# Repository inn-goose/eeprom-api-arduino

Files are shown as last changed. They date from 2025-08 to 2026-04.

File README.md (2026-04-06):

# Arduino EEPROM Programmer for AT28C64 / AT28C256

An Arduino-based parallel EEPROM programmer for the AT28Cxx chip family (AT28C04, AT28C16, AT28C64, AT28C256) with a Python CLI. Validated on Arduino MEGA and DUE. Useful for [Ben Eater's breadboard computer](https://eater.net/) projects and similar builds.

> [!CAUTION]
> During **read** and **standalone verify** operations, the chip's `!WE` pin **MUST** be connected to `VCC` using a jumper wire to prevent data corruption from Arduino's reset behavior. The `--write` command includes in-session verify and does not require the jumper. [Details](https://goose.sh/blog/eeprom-programmer-5-data-corruption/)

> [!IMPORTANT]
> This project concerns **external** EEPROM chips, not the built-in Arduino EEPROM memory.

The firmware is flashed onto an Arduino MEGA or DUE. The EEPROM chip is connected to the extended pin header (pins 22-53), and the Python CLI communicates over a binary serial protocol to erase, write, read, and verify binary data. The CLI interface is modeled after [`minipro`](https://formulae.brew.sh/formula/minipro) (XGecu programmer).

A companion blog series documents the development: [EEPROM Programmer posts on goose.sh](https://goose.sh/tags/eeprom-programmer/).

## Supported Chips

* `AT28C04 @ DIP24`, [datasheet](https://www.tvsat.com.pl/pdf/A/at28c04_atm.pdf)
* `AT28C16 @ DIP24`, [datasheet](http://cva.stanford.edu/classes/cs99s/datasheets/at28c16.pdf)
* `AT28C64 @ DIP28`, [datasheet](https://ww1.microchip.com/downloads/en/devicedoc/doc0001H.pdf)
* `AT28C256 @ DIP28`, [datasheet](https://ww1.microchip.com/downloads/en/DeviceDoc/doc0006.pdf)

Details in the [EEPROM Programmer: Supported Chips](https://goose.sh/blog/eeprom-programmer-8-supported-chips/) post.

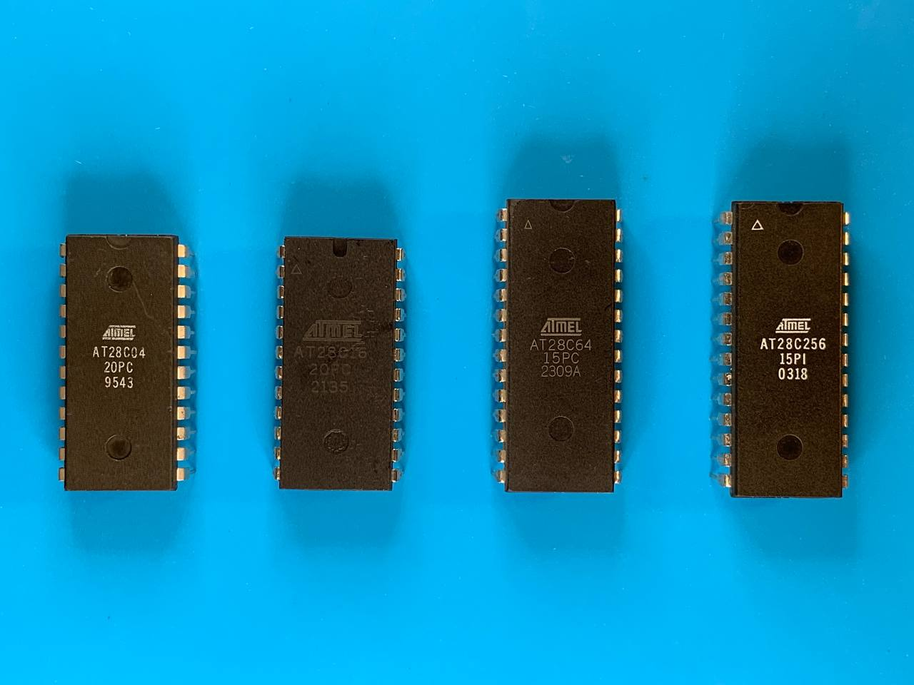
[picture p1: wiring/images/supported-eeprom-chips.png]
Supported EEPROM Chips


## Performance

The programmer's performance is strongly dependent on the Arduino platform; the DUE is ~30% faster than the MEGA for reads, and significantly faster for writes due to page write support. The performance measurement details are described in the [EEPROM Programmer Performance](https://goose.sh/blog/eeprom-programmer-8-supported-chips/#eeprom-programmer-performance) post.

### Arduino DUE, 84 MHz (binary protocol)

| Chip | Size | Read (sec) | Erase + Write + Verify (sec) |
| -- | :--: | :--: | :--: |
| AT28C64 | 8K x 8 | 1.6 | 12.7 |

### Arduino DUE, 84 MHz (JSON-RPC, legacy)

| Chip | Size | Full Memory Read (sec) | Full Memory Write (sec) |
| -- | :--: | :--: | :--: |
| AT28C04 | 512 x 8 | 0.9 | 1.4 |
| AT28C16 | 2K x 8 | 3.6 | 11 |
| AT28C64 | 8K x 8 | 15 | 22 |
| AT28C256 | 32K x 8 | 56 | 85* |

(*) if [page write](https://goose.sh/blog/eeprom-programmer-7-page-write/) mode is enabled.

### Arduino MEGA, 16 MHz (JSON-RPC, legacy)

| Chip | Size | Full Memory Read (sec) | Full Memory Write (sec) |
| -- | :--: | :--: | :--: |
| AT28C04 | 512 x 8 | 1.4 | 1.8 |
| AT28C16 | 2K x 8 | 5.5 | 14 |
| AT28C64 | 8K x 8 | 21 | 28* |
| AT28C256 | 32K x 8 | 84 | 305 |

(*) if [RDY/!BUSY polling](https://goose.sh/blog/eeprom-programmer-6-data-polling-vs-rdy-busy/#rdybusy-pin-polling) mode is enabled

## Data Corruption and Read-Only Jumper Wire

Communication over the Serial protocol can corrupt data stored in the EEPROM memory, despite the **Hardware Protection** claimed in the datasheet. This issue is analyzed in detail in the [Data Corruption on Arduino Serial Connection Reset](https://goose.sh/blog/eeprom-programmer-5-data-corruption/) post.

To prevent data corruption, the Read-Only jumper wire should always be used during read operations, as shown in the wiring diagrams. The jumper should be removed only when writing data to the chip.

The `--write` command performs erase, write, and verify in a single serial session without reconnecting, so the jumper is not needed for write+verify operations.

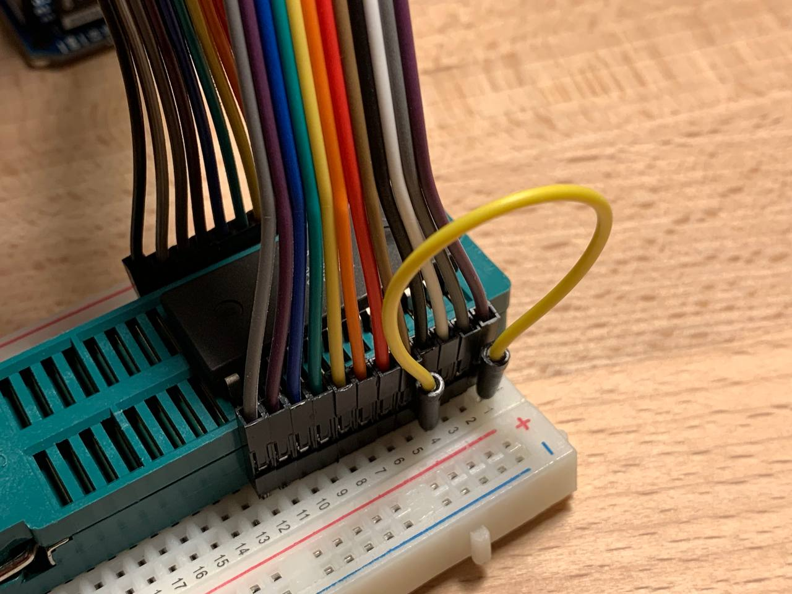
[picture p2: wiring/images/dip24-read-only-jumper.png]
Read Only Jumper Wire


## Wiring

The Programmer supports two chip wiring variants: `DIP24` and `DIP28`. Each type requires its own wiring configuration and a recompilation of the code. Below is a mapping table along with the section of code that must be adjusted accordingly.

| Wiring Type | Supported Chips |
| -- | -- |
| DIP24 | AT28C04, AT28C16 |
| DIP28 | AT28C64, AT28C256 |

file: [./eeprom_programmer/eeprom_programmer.ino](./eeprom_programmer/eeprom_programmer.ino)
```cpp
// EEPROM Programmer

// specify the wiring type here
// * DIP24
// * DIP28
static EepromProgrammer eeprom_programmer(BoardWiringType::DIP24);
// static EepromProgrammer eeprom_programmer(BoardWiringType::DIP28);
```

The wiring configuration can be reconfigured in the file [./eeprom_programmer/board_wiring.h](./eeprom_programmer/board_wiring.h)

### DIP24 wiring

The pins are arranged sequentially to simplify wiring. On one side, the pins start with GND, and on the other with VCC, eliminating the need for separate power wires.

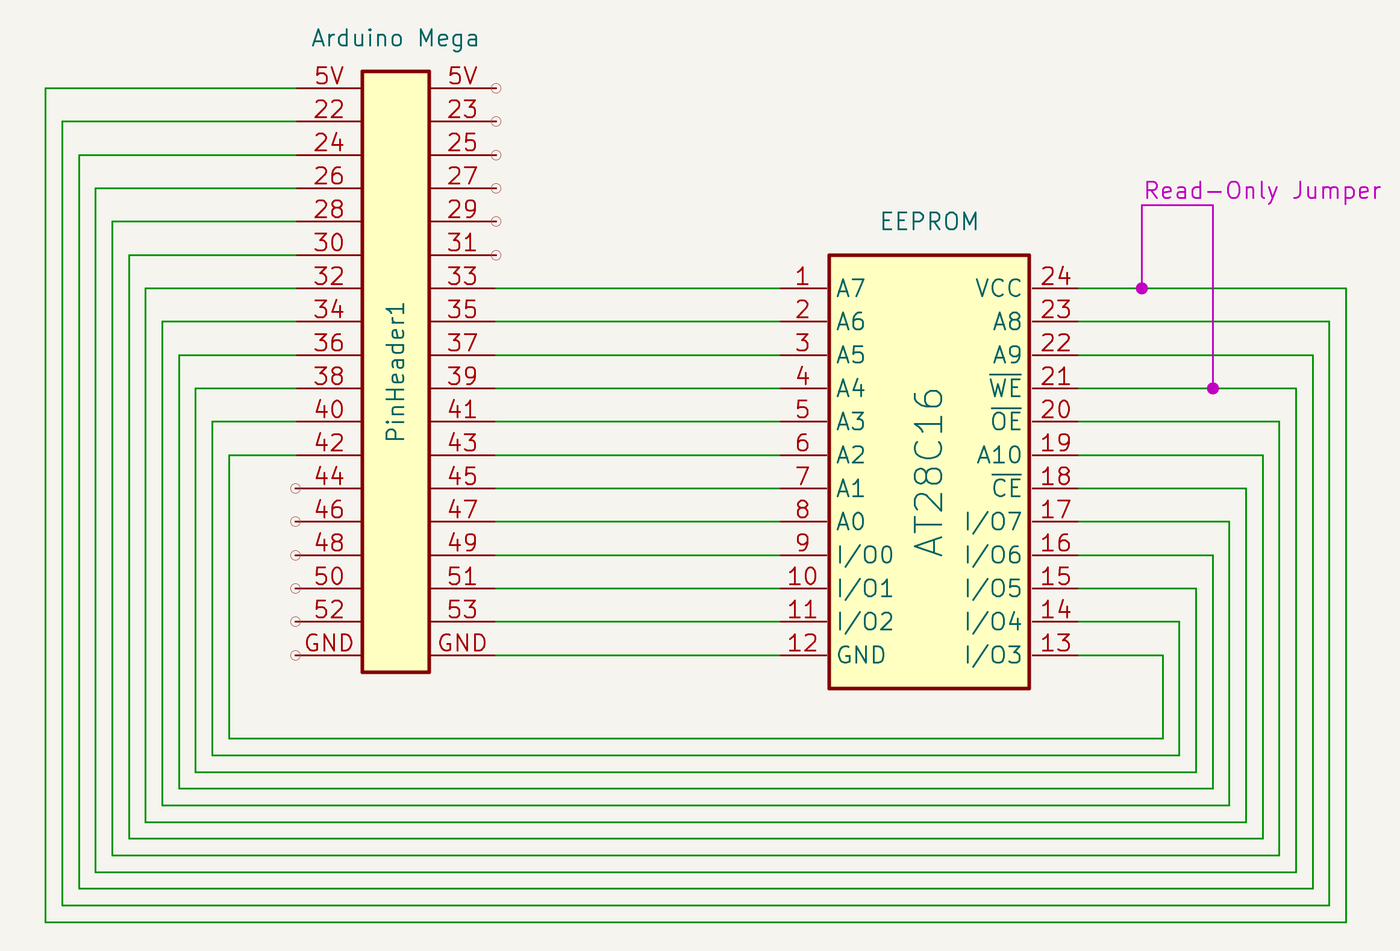
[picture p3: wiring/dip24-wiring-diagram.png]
EEPROM Programmer Wiring DIP24 Diagram


### DIP28 wiring

For the `DIP28` variant, two additional wires are added on each side.

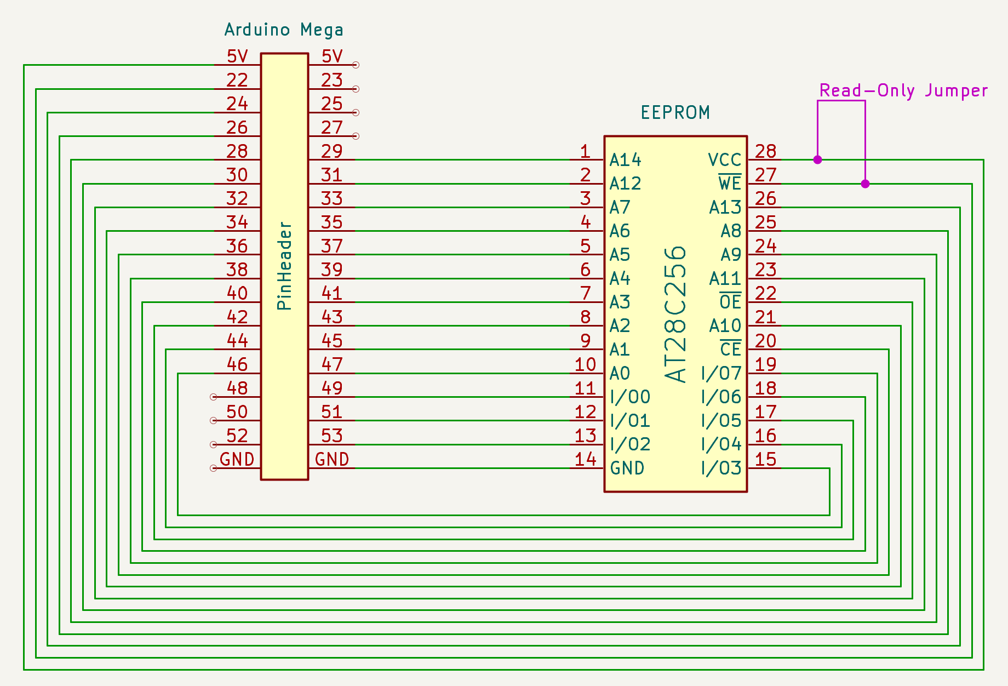
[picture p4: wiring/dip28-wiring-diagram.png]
EEPROM Programmer Wiring DIP28 Diagram


### Wiring example

In the photographs, a short breadboard was used for the `DIP24` wiring, along with two ribbon cables and a ZIF socket for convenience. This setup is not mandatory: simple jumper wires can be used instead, and the chip may be placed directly into the breadboard.

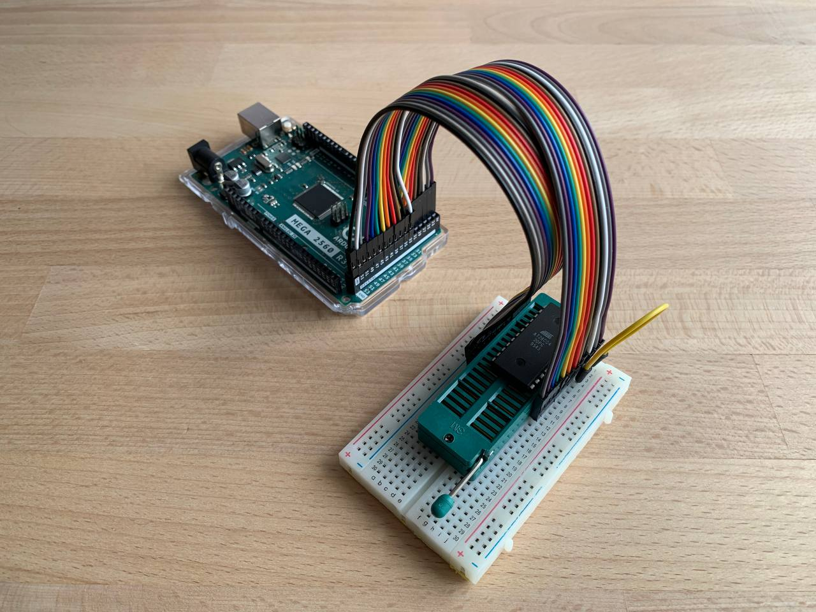
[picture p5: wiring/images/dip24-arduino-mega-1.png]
DIP24 Wiring with Arduino MEGA

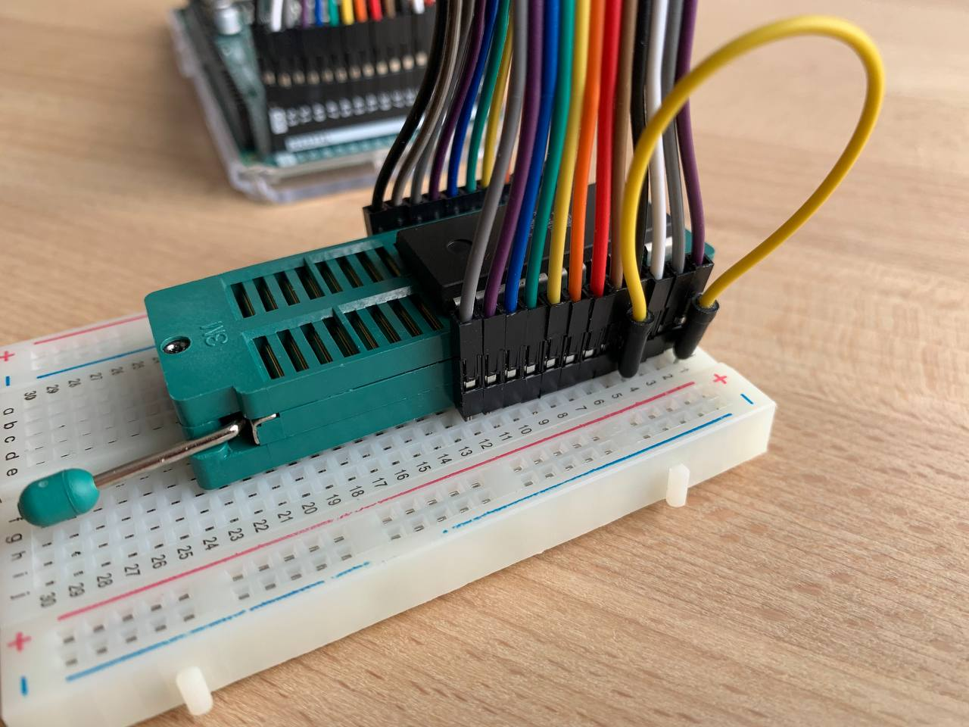
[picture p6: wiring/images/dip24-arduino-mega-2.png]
DIP24 Wiring with Arduino MEGA

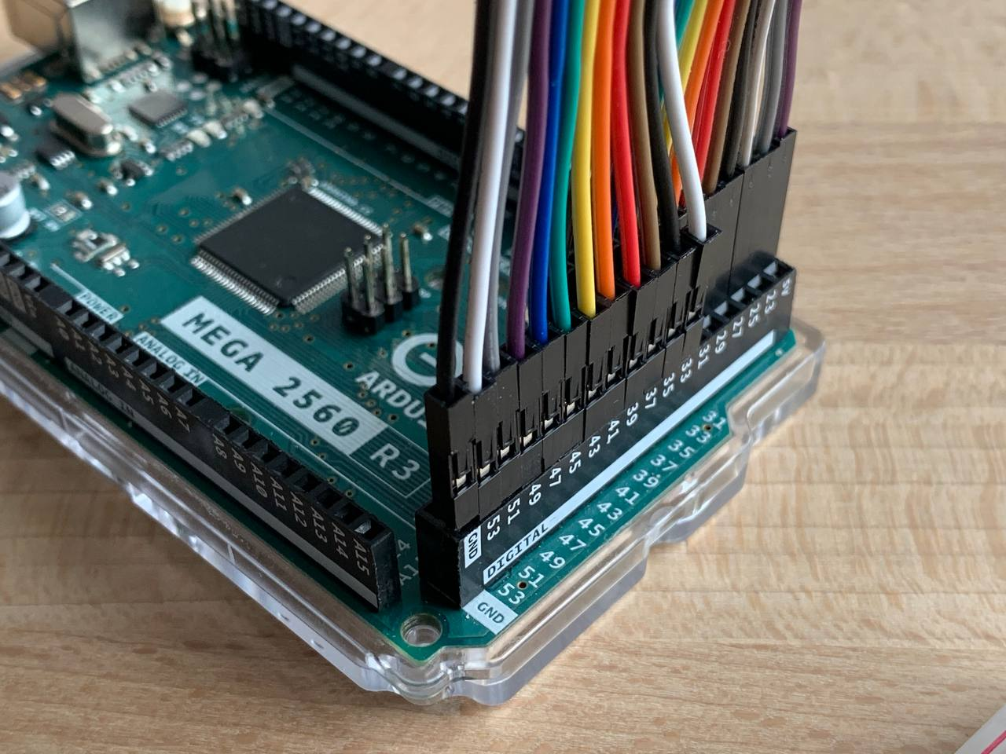
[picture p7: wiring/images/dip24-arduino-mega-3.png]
DIP24 Wiring with Arduino MEGA


## Programming EEPROM Chips with CLI

A Python CLI enables reading and writing large volumes of data. When using only the Arduino, it is not possible to program a 64 KB chip, as this does not fit into the MEGA's memory.

The CLI communicates with the firmware over a binary serial protocol with CRC-16 integrity checking. The previous JSON-RPC implementation is described in the [Implementing Serial JSON-RPC API](https://goose.sh/blog/eeprom-programmer-4-serial-json-rpc-api/) post.

### Initialization

```bash
pip3 install virtualenv

# get the python version
python --version
...
Python 3.9.6

# specify python version here (use only X.Y part)
PATH=${PATH}:~/Library/Python/3.9/bin/ ./env/init.sh

# activate the newly created venv
source venv/bin/activate

# add the CLI library to the python path
export PYTHONPATH=./eeprom_programmer_cli/:$PYTHONPATH
```

### Serial port selection

The CLI must be provided with the port to which the Arduino is connected. The port name can be found in the Arduino IDE or obtained by listing available ports using the following command:

```bash
python3 -m serial.tools.list_ports
...
/dev/cu.usbmodem2101
```

### Supported commands

The CLI interface closely resembles the `minipro` interface used with *XGecu* programmers.

#### read

```bash
# read data from the chip memory and write it to a binary file
./eeprom_programmer_cli/cli.py /dev/cu.usbmodem2101 -p AT28C64 --read tmp/dump_eeprom.bin

# read the binary file content with xxd
xxd tmp/dump_eeprom.bin | less
```

#### erase

```bash
# erase the chip memory with the specific pattern
./eeprom_programmer_cli/cli.py /dev/cu.usbmodem2101 -p AT28C64 --erase --erase-pattern FF
```

#### write

The `--write` command performs erase + write + verify in a single serial session. Verify runs automatically after writing, without reconnecting to the board.

```bash
# erase + write + verify (default)
./eeprom_programmer_cli/cli.py /dev/cu.usbmodem2101 -p AT28C64 --write test_bin/64_the_red_migration.bin

# skip verify after write
./eeprom_programmer_cli/cli.py /dev/cu.usbmodem2101 -p AT28C64 --write test_bin/64_the_red_migration.bin --skip-verify

# do not erase the chip content before the write operation
./eeprom_programmer_cli/cli.py /dev/cu.usbmodem2101 -p AT28C64 --write test_bin/64_the_red_migration.bin --skip-erase

# use custom erase pattern
./eeprom_programmer_cli/cli.py /dev/cu.usbmodem2101 -p AT28C64 --write test_bin/64_the_red_migration.bin --erase-pattern CC
```

#### verify

Standalone verify reads the chip and compares against a binary file. Requires the `!WE` jumper wire to prevent data corruption on reconnect.

```bash
# read data and verify it against the binary file
./eeprom_programmer_cli/cli.py /dev/cu.usbmodem2101 -p AT28C64 --verify test_bin/64_the_red_migration_AT28C64_ff.bin
```

## Troubleshooting

### Programmer error codes

Check [./eeprom_programmer/eeprom_programmer_lib.h](./eeprom_programmer/eeprom_programmer_lib.h) for error codes:
```cpp
enum ErrorCode : short {
  SUCCESS = 0,
  ...
```

### Failed to init AT28C256 chip with error: 12

An unknown chip type, or a mismatch between the wiring configuration and the selected chip type. Check the DIP24 or DIP28 wiring.

```bash
init device: failed, failed to init AT28C256 chip with: error response: {'code': -32010, 'message': 'Programmer error', 'data': 'Failed to init AT28C256 chip with error: 12'}
```

On startup, the CLI reports the board wiring type that the programmer firmware was built with:
```bash
programmer_settings: {'board_wiring_type': 24, 'max_page_size': 64}
```

## Testing

### Basic CLI tests

#### prepare

```bash
source venv/bin/activate
export PYTHONPATH=./eeprom_programmer_cli/:$PYTHONPATH
```

#### write + verify (in-session)

No jumper swapping needed. The `--write` command performs erase, write, and verify in a single serial session.

```bash
./eeprom_programmer_cli/cli.py /dev/cu.usbmodem2101 -p AT28C64 --write test_bin/64_the_red_migration_AT28C64_ff.bin --collect-performance
```

#### erase

```bash
# >> remove jumper wire
./eeprom_programmer_cli/cli.py /dev/cu.usbmodem2101 -p AT28C64 --erase --erase-pattern BB --collect-performance

# >> set jumper wire
./eeprom_programmer_cli/cli.py /dev/cu.usbmodem2101 -p AT28C64 --read tmp/dump_eeprom.bin

xxd tmp/dump_eeprom.bin | less
```

#### write and read

```bash
# >> remove jumper wire
./eeprom_programmer_cli/cli.py /dev/cu.usbmodem2101 -p AT28C64 --write test_bin/64_the_red_migration.bin --erase-pattern BB --collect-performance

# >> set jumper wire
./eeprom_programmer_cli/cli.py /dev/cu.usbmodem2101 -p AT28C64 --read tmp/dump_eeprom.bin

xxd tmp/dump_eeprom.bin > tmp/dump_eeprom.hex
vimdiff tmp/dump_eeprom.hex tmp/64_the_red_migration.hex
```

#### standalone verify

```bash
# >> remove jumper wire
./eeprom_programmer_cli/cli.py /dev/cu.usbmodem2101 -p AT28C64 --write test_bin/64_the_red_migration.bin --skip-verify --collect-performance

# >> set jumper wire
./eeprom_programmer_cli/cli.py /dev/cu.usbmodem2101 -p AT28C64 --verify test_bin/64_the_red_migration_AT28C64_ff.bin
```

### Performance testing with CLI

```bash
# AT28C04
./eeprom_programmer_cli/cli.py /dev/cu.usbmodem2101 -p AT28C04 --erase --erase-pattern 11 --collect-performance
./eeprom_programmer_cli/cli.py /dev/cu.usbmodem2101 -p AT28C04 --read tmp/dump_eeprom.bin --collect-performance && xxd tmp/dump_eeprom.bin | less
./eeprom_programmer_cli/cli.py /dev/cu.usbmodem2101 -p AT28C04 --write test_bin/4_journey_of_luna_AT28C04_ff.bin --skip-erase --collect-performance
./eeprom_programmer_cli/cli.py /dev/cu.usbmodem2101 -p AT28C04 --verify test_bin/4_journey_of_luna_AT28C04_ff.bin --collect-performance

# AT28C16
./eeprom_programmer_cli/cli.py /dev/cu.usbmodem2101 -p AT28C16 --erase --erase-pattern 11 --collect-performance
./eeprom_programmer_cli/cli.py /dev/cu.usbmodem2101 -p AT28C16 --read tmp/dump_eeprom.bin --collect-performance && xxd tmp/dump_eeprom.bin | less
./eeprom_programmer_cli/cli.py /dev/cu.usbmodem2101 -p AT28C16 --write test_bin/16_geese_in_space_AT28C16_ff.bin --skip-erase --collect-performance
./eeprom_programmer_cli/cli.py /dev/cu.usbmodem2101 -p AT28C16 --verify test_bin/16_geese_in_space_AT28C16_ff.bin --collect-performance

# AT28C64
./eeprom_programmer_cli/cli.py /dev/cu.usbmodem2101 -p AT28C64 --erase --erase-pattern 11 --collect-performance
./eeprom_programmer_cli/cli.py /dev/cu.usbmodem2101 -p AT28C64 --read tmp/dump_eeprom.bin --collect-performance && xxd tmp/dump_eeprom.bin | less
./eeprom_programmer_cli/cli.py /dev/cu.usbmodem2101 -p AT28C64 --write test_bin/64_the_red_migration_AT28C64_ff.bin --skip-erase --collect-performance
./eeprom_programmer_cli/cli.py /dev/cu.usbmodem2101 -p AT28C64 --verify test_bin/64_the_red_migration_AT28C64_ff.bin --collect-performance

# AT28C256
./eeprom_programmer_cli/cli.py /dev/cu.usbmodem2101 -p AT28C256 --erase --erase-pattern 11 --collect-performance
./eeprom_programmer_cli/cli.py /dev/cu.usbmodem2101 -p AT28C256 --read tmp/dump_eeprom.bin --collect-performance && xxd tmp/dump_eeprom.bin | less
./eeprom_programmer_cli/cli.py /dev/cu.usbmodem2101 -p AT28C256 --write test_bin/256_the_geometry_of_flight_AT28C256_ff.bin --skip-erase --collect-performance
./eeprom_programmer_cli/cli.py /dev/cu.usbmodem2101 -p AT28C256 --verify test_bin/256_the_geometry_of_flight_AT28C256_ff.bin --collect-performance
```

### Using XGecu programmer as a reference

Use the [`minipro`](https://formulae.brew.sh/formula/minipro) utility to perform read and write operations with the XGecu programmer

```bash
brew install minipro

# write the "real" dump to the chip
minipro --device AT28C64 -s -u --write test_bin/64_the_red_migration.bin
minipro --device AT28C256 -s -u --write test_bin/256_the_geometry_of_flight.bin

# read the data
minipro --device AT28C64 -u --read tmp/dump_xgecu.bin
minipro --device AT28C256 -u --read tmp/dump_xgecu.bin

# convert to HEX
xxd tmp/dump_xgecu.bin > tmp/dump_xgecu.hex

# compare
vimdiff tmp/dump_eeprom.hex tmp/dump_xgecu.hex
```

### JSON-RPC API (legacy, no longer active)

The firmware previously used JSON-RPC over serial. These commands no longer work with the current binary protocol firmware but are preserved here for reference. See the [Implementing Serial JSON-RPC API](https://goose.sh/blog/eeprom-programmer-4-serial-json-rpc-api/) post for details.

Set Arduino IDE's *Serial Monitor* on `115200` baud

`init_chip(chip_type: str)`
```json
{"jsonrpc":"2.0", "id":0, "method": "init_chip", "params": ["AT28C64"]}
```

`set_read_mode(page_size_bytes: int)`
```json
{"jsonrpc":"2.0", "id":0, "method": "set_read_mode", "params": [4]}
```

`read_page(page_no: int)`
```json
{"jsonrpc":"2.0", "id":0, "method": "read_page", "params": [0]}
```

`set_write_mode(page_size_bytes: int)`
```json
{"jsonrpc":"2.0", "id":0, "method": "set_write_mode", "params": [4]}
```

`write_page(page_no: int, data: array[int])`
```json
{"jsonrpc":"2.0", "id":0, "method": "write_page","params": [0, [127, 127, 127, 127]]}
```

#### write operation sequence

```json
{"jsonrpc":"2.0", "id":0, "method": "init_chip", "params": ["AT28C64"]}
{"jsonrpc":"2.0", "id":0, "method": "set_write_mode", "params": [4]}
{"jsonrpc":"2.0", "id":0, "method": "write_page","params": [0, [120, 130, 140, 150]]}
{"jsonrpc":"2.0", "id":0, "method": "write_page","params": [50, [20, 30, 40, 50]]}
{"jsonrpc":"2.0", "id":0, "method": "get_write_perf","params": []}
```

#### read operation sequence

```json
{"jsonrpc":"2.0", "id":0, "method": "init_chip", "params": ["AT28C64"]}
{"jsonrpc":"2.0", "id":0, "method": "set_read_mode", "params": [4]}
{"jsonrpc":"2.0", "id":0, "method": "read_page", "params": [0]}
{"jsonrpc":"2.0", "id":0, "method": "read_page", "params": [50]}
```

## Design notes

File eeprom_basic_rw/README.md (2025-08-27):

# EEPROM 28C64 Basic RW Example for Arduino

## Init

set pins layout in `eeprom_wiring.h`

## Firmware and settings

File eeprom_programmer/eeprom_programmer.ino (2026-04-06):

#include "board_wiring.h"
#include "eeprom_programmer_lib.h"
#include "binary_protocol.h"

using namespace EepromProgrammerLibrary;
using namespace BoardWiring;
using namespace BinaryProtocol;


// EEPROM Programmer

// specify the wiring type here
// * DIP24
// * DIP28
// static EepromProgrammer eeprom_programmer(BoardWiringType::DIP24);
static EepromProgrammer eeprom_programmer(BoardWiringType::DIP28);


// Binary Protocol Processor

static BinaryProtocolBoard binary_board(command_handler);

void command_handler(uint8_t cmd, uint8_t seq, const uint8_t* payload, uint16_t payload_len) {
  if (cmd == CMD_INIT_CHIP) {
    // payload: chip_name (null-terminated string)
    if (payload_len < 1) {
      binary_board.send_error(cmd, seq, ErrorCode::CHIP_NOT_SUPPORTED, "empty chip name");
      return;
    }
    const char* chip_name = (const char*)payload;

    ErrorCode code = eeprom_programmer.init_chip(String(chip_name));
    if (code != ErrorCode::SUCCESS) {
      char buf[50];
      snprintf(buf, sizeof(buf), "init failed: %d", code);
      binary_board.send_error(cmd, seq, code, buf);
      return;
    }

    // response payload: memory_size as uint32 LE (explicit serialization)
    uint32_t mem_size = eeprom_programmer.get_memory_size_bytes();
    uint8_t mem_size_le[4] = {
      (uint8_t)(mem_size & 0xFF),
      (uint8_t)((mem_size >> 8) & 0xFF),
      (uint8_t)((mem_size >> 16) & 0xFF),
      (uint8_t)((mem_size >> 24) & 0xFF),
    };
    binary_board.send_response(cmd, seq, mem_size_le, 4);

  } else if (cmd == CMD_SET_READ_MODE) {
    // payload: page_size as uint16 LE
    if (payload_len < 2) {
      binary_board.send_error(cmd, seq, ErrorCode::INVALID_PAGE_SIZE, "missing page_size");
      return;
    }
    uint16_t page_size = payload[0] | ((uint16_t)payload[1] << 8);

    ErrorCode code = eeprom_programmer.set_read_mode(page_size);
    if (code != ErrorCode::SUCCESS) {
      char buf[50];
      snprintf(buf, sizeof(buf), "set_read_mode failed: %d", code);
      binary_board.send_error(cmd, seq, code, buf);
      return;
    }

    binary_board.send_response(cmd, seq, nullptr, 0);

  } else if (cmd == CMD_READ_PAGE) {
    // payload: page_no as uint16 LE
    if (payload_len < 2) {
      binary_board.send_error(cmd, seq, ErrorCode::INVALID_PAGE_NO, "missing page_no");
      return;
    }
    uint16_t page_no = payload[0] | ((uint16_t)payload[1] << 8);

    const size_t page_size = eeprom_programmer.get_page_size_bytes();
    uint8_t buffer[page_size];

    ErrorCode code = eeprom_programmer.read_page(page_no, buffer);
    if (code != ErrorCode::SUCCESS) {
      char buf[50];
      snprintf(buf, sizeof(buf), "read_page %d failed: %d", page_no, code);
      binary_board.send_error(cmd, seq, code, buf);
      return;
    }

    binary_board.send_response(cmd, seq, buffer, page_size);

  } else if (cmd == CMD_SET_WRITE_MODE) {
    // payload: page_size as uint16 LE
    if (payload_len < 2) {
      binary_board.send_error(cmd, seq, ErrorCode::INVALID_PAGE_SIZE, "missing page_size");
      return;
    }
    uint16_t page_size = payload[0] | ((uint16_t)payload[1] << 8);

    ErrorCode code = eeprom_programmer.set_write_mode(page_size);
    if (code != ErrorCode::SUCCESS) {
      char buf[50];
      snprintf(buf, sizeof(buf), "set_write_mode failed: %d", code);
      binary_board.send_error(cmd, seq, code, buf);
      return;
    }

    binary_board.send_response(cmd, seq, nullptr, 0);

  } else if (cmd == CMD_WRITE_PAGE) {
    // payload: page_no(uint16 LE) + data(uint8[N])
    if (payload_len < 3) {
      binary_board.send_error(cmd, seq, ErrorCode::INVALID_PAGE_NO, "missing page_no or data");
      return;
    }
    uint16_t page_no = payload[0] | ((uint16_t)payload[1] << 8);
    const uint8_t* data = payload + 2;
    uint16_t data_len = payload_len - 2;

    ErrorCode code = eeprom_programmer.write_page(page_no, data, data_len);
    if (code != ErrorCode::SUCCESS) {
      char buf[50];
      snprintf(buf, sizeof(buf), "write_page %d failed: %d", page_no, code);
      binary_board.send_error(cmd, seq, code, buf);
      return;
    }

    binary_board.send_response(cmd, seq, nullptr, 0);

  } else if (cmd == CMD_GET_READ_PERF) {
    const size_t page_size = eeprom_programmer.get_page_size_bytes();
    unsigned int timings[page_size];
    eeprom_programmer.get_read_byte_usec_for_page(timings, page_size);

    // serialize as uint16 LE array (explicit byte order)
    uint8_t timings_le[page_size * 2];
    for (size_t i = 0; i < page_size; i++) {
      timings_le[i * 2] = (uint8_t)(timings[i] & 0xFF);
      timings_le[i * 2 + 1] = (uint8_t)((timings[i] >> 8) & 0xFF);
    }
    binary_board.send_response(cmd, seq, timings_le, page_size * 2);

  } else if (cmd == CMD_GET_WRITE_PERF) {
    const size_t page_size = eeprom_programmer.get_page_size_bytes();
    unsigned int timings[page_size];
    eeprom_programmer.get_write_byte_usec_for_page(timings, page_size);

    // serialize as uint16 LE array (explicit byte order)
    uint8_t timings_le[page_size * 2];
    for (size_t i = 0; i < page_size; i++) {
      timings_le[i * 2] = (uint8_t)(timings[i] & 0xFF);
      timings_le[i * 2 + 1] = (uint8_t)((timings[i] >> 8) & 0xFF);
    }
    binary_board.send_response(cmd, seq, timings_le, page_size * 2);

  } else {
    // protocol-level error: not from EepromProgrammer ErrorCode enum
    binary_board.send_error(cmd, seq, 0xFFFF, "unknown command");
  }
}


// Arduino

void setup() {
  // protocol board
  binary_board.init();
  // eeprom programmer
  eeprom_programmer.init_programmer();
  // send boot frame
  binary_board.send_boot(
    (uint8_t)eeprom_programmer.get_board_wiring_type(),
    (uint8_t)eeprom_programmer.get_max_page_size());
}

void loop() {
  binary_board.loop();
}

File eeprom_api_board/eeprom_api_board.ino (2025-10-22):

#include "eeprom_wiring.h"
#include "eeprom_api.h"
#include "serial_json_rpc.h"

using namespace EepromApiLibrary;
using namespace SerialJsonRpcLibrary;


// EEPROM API

static EepromApi eeprom_api(
  // address
  EEPROM_ADDRESS_PINS,
  // data
  EEPROM_DATA_PINS,
  // management
  EEPROM_CHIP_ENABLE_PIN,
  EEPROM_OUTPUT_ENABLE_PIN,
  EEPROM_WRITE_ENABLE_PIN,
  // status
  EEPROM_READY_BUSY_OUTPUT_PIN);


// Serial JSON RPC Processor

static SerialJsonRpcBoard rpc_board(rpc_processor);

void rpc_processor(int request_id, const String &method, const String params[], int params_size) {
  if (method == "init_read") {
    if (params_size != 1) {
      rpc_board.send_error(request_id, -32602, "Invalid params", "params_size != 1");
      return;
    }

    String eeprom_type = params[0];

    eeprom_api.readInit();

    rpc_board.send_result_string(request_id, "OK. Initialized");

  } else if (method == "read_page") {
    if (params_size != 2) {
      rpc_board.send_error(request_id, -32602, "Invalid params", "params_size != 2");
      return;
    }

    const int page_size_bytes = atoi(params[0].c_str());
    const int page_no = atoi(params[1].c_str());

    uint8_t buffer[page_size_bytes];
    const int start = page_size_bytes * page_no;
    for (int i = 0; i < page_size_bytes; i ++) {
      buffer[i] = eeprom_api.readData(start + i);
    }

    rpc_board.send_result_bytes(request_id, buffer, page_size_bytes);

  } else {
    rpc_board.send_error(request_id, -32601, "Method not found", method.c_str());
  }
}


// Arduino

void setup() {
  // rpc board
  rpc_board.init();
  // eeprom api
  eeprom_api.init();
}

void loop() {
  rpc_board.loop();
}

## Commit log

2025-08-30 connect READY/BUSY pin as open drain output
2025-08-30 implement wait on BUSY pin after WE
2025-09-18 fix wiring diagram
2025-10-21 new send_result_bytes method for JSON RPC board
2025-11-16 refactor wiring. add DIP24
2025-12-21 rename methods to snake case
2025-12-22 fix giga compilation errors
    [eeprom_programmer.ino, eeprom_programmer_lib.h]
2025-12-23 add wiring diagram for AT28C16
    [eeprom_programmer.kicad_sch]
2025-12-24 fix chip settings propagation
    [eeprom_programmer.ino]
2025-12-24 add comments; fix wiring diagrams
    [eeprom_programmer.kicad_sch]
2025-12-26 fix chip init procedure
    [eeprom_programmer.ino, eeprom_programmer_lib.h]
2025-12-26 update wiring diagrams
    [eeprom_programmer.kicad_sch]
2026-04-03 fix bugs: buffer overflows, uninitialized vars, wrong array size, dead code
    [eeprom_programmer_lib.h]
2026-04-06 add WE pin corruption research, binary protocol plan, ArduinoJson v7 findings
2026-04-06 add in-session write+verify to CLI, switch to DIP28 wiring for AT28C64
2026-04-06 fix pow() float and micros() overflow bugs in eeprom_programmer_lib.h
    [eeprom_programmer_lib.h]
2026-04-06 add binary_protocol.h: frame protocol, state machine receiver, single-write sender
2026-04-06 wire binary protocol in firmware and Python CLI, replace JSON-RPC
    [client.py, eeprom_programmer.ino, test_client.py]
